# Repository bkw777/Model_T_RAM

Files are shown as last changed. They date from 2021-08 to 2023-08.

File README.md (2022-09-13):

# Model_T_RAM
8K RAM module for "Model T Computers"  
* TRS-80 Model 100  
* Kyotronic KC-85  
* NEC PC-8201  
* Olivetti M10  

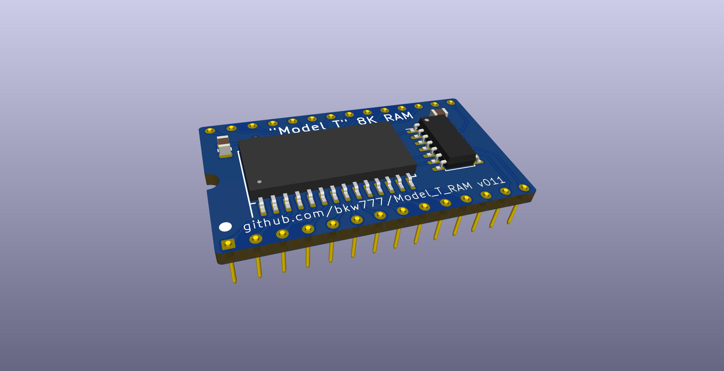
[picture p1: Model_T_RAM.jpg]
  


Gerbers available in [releases](../../releases/latest).

[PCB from OSHPark](https://oshpark.com/shared_projects/dh91gDhY)  
[PCB from PCBWAY](https://www.pcbway.com/project/shareproject/Model_T_RAM.html)

[BOM from DigiKey](https://www.digikey.com/short/vbnv3rnf)

[How to do the legs](https://gist.github.com/bkw777/52d85d89eeff8445cc667685d05ea94d)  

The DIP row spacing is actually 725 mils not 700. It makes it annoying to solder because the rows don't line up exactly with the rows in a breadboard, but it's not an error.  
Using a set of single row socket headers in the breadboard, or even two stacked, allows the socket headers to spread a little and make it easier to hold the pins and pcb for soldering, and the finished soldered pins aren't pinched inwards too badly.

----
Thanks to Steve Adolph for advice about RAM_RST

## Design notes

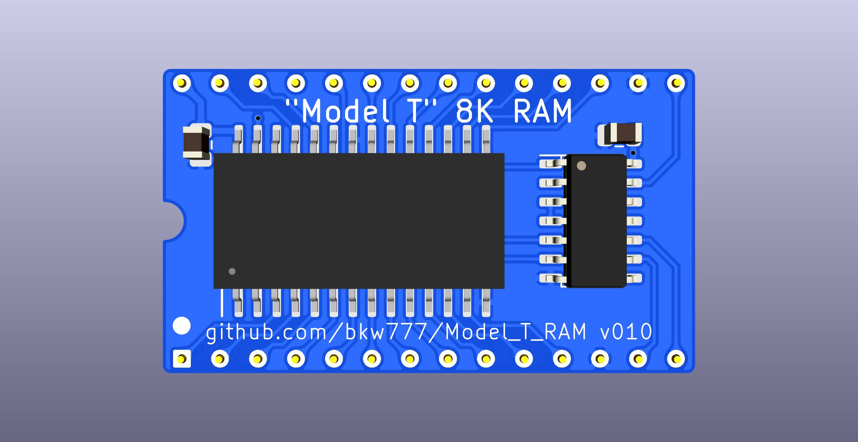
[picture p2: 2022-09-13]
Model_T_RAM_top.jpg

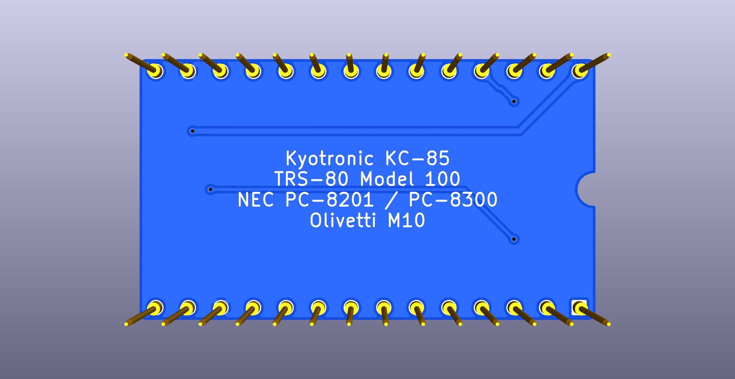
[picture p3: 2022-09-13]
Model_T_RAM_bottom.jpg

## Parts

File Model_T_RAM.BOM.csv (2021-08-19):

Index | Quantity | Part Number | Manufacturer Part Number | Description | Customer Reference | Available | Backorder | Unit Price | Extended Price USD
1 | 1 | 1450-1037-ND | AS6C6264-55SCN | IC SRAM 64KBIT PARALLEL 28SOP |  | 1 | 0 | 3.21000 | 3.21
2 | 50 | A117856CT-ND | 1544210-2 | SIL CONTACT Y1 THROUGH HOLE |  | 50 | 0 | 0.03040 | 1.52
3 | 1 | MC74HCT86ADR2GOSCT-ND | MC74HCT86ADR2G | IC GATE XOR 4CH 2-INP 14SOIC |  | 1 | 0 | 0.49000 | 0.49
4 | 2 | 732-8045-1-ND | 885012207045 | CAP CER 0.1UF 16V X7R 0805 |  | 2 | 0 | 0.10000 | 0.20

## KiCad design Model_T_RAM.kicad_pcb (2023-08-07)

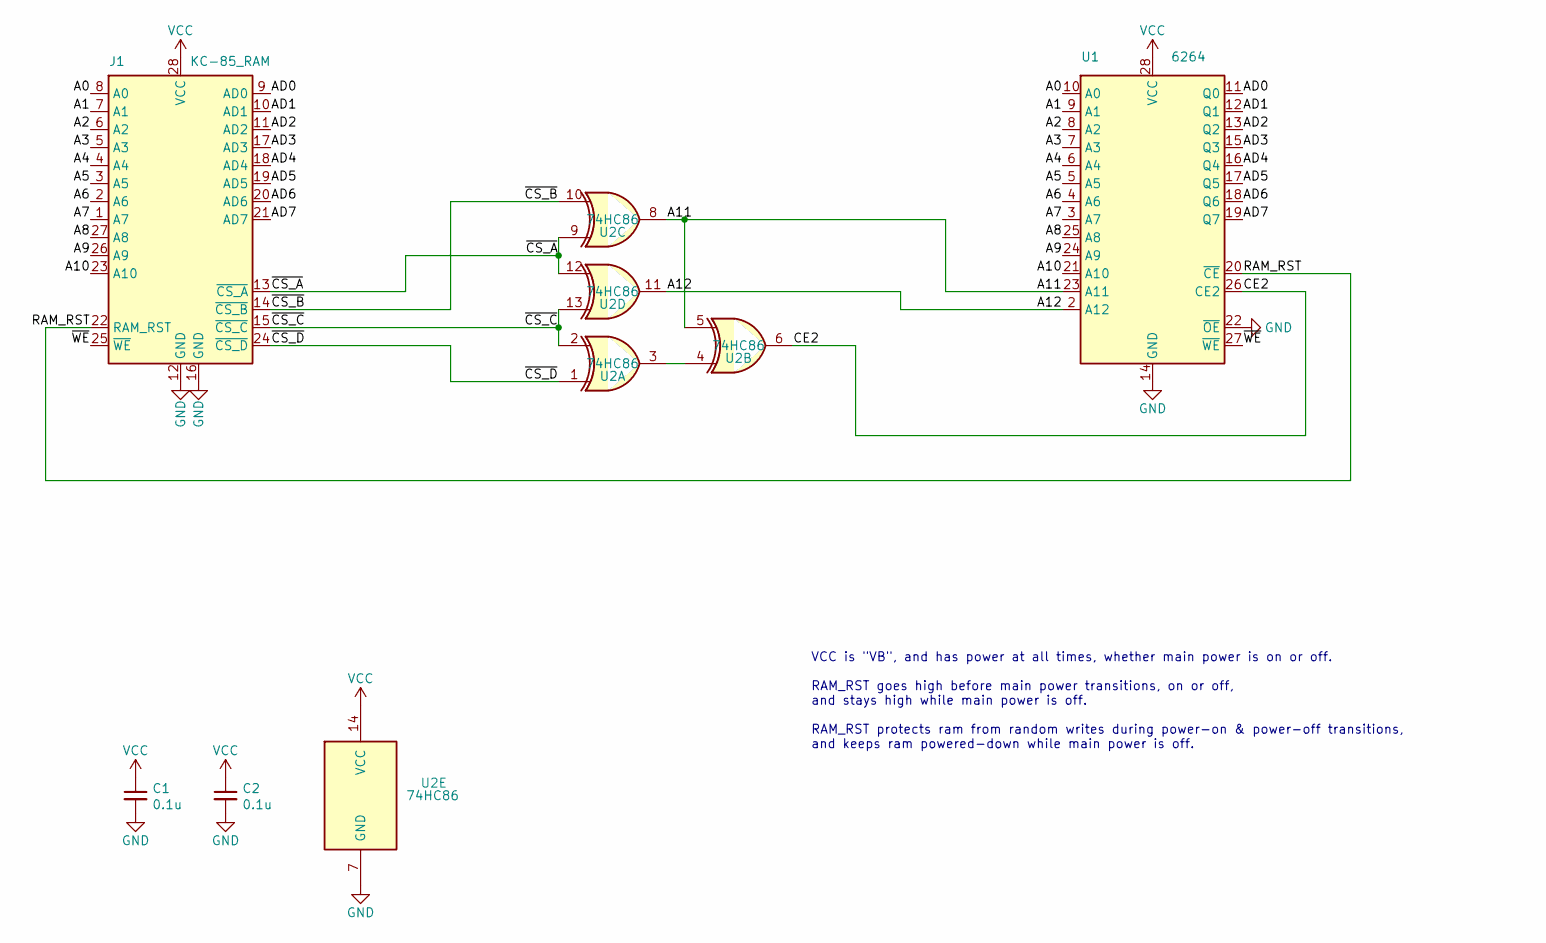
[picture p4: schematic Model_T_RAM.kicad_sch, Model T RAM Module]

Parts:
C1, C2: 0.1u; C_0805
J1: KC-85_RAM; DIP28_725mils_pcb_pins
U1: 6264; SSOP-28
U2: 74HC86; SOIC-14_4x9

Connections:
/A0: J1.8 (A0), U1.10 (A0)
/A1: J1.7 (A1), U1.9 (A1)
/A2: J1.6 (A2), U1.8 (A2)
/A3: J1.5 (A3), U1.7 (A3)
/A4: J1.4 (A4), U1.6 (A4)
/A5: J1.3 (A5), U1.5 (A5)
/A6: J1.2 (A6), U1.4 (A6)
/A7: J1.1 (A7), U1.3 (A7)
/A8: J1.27 (A8), U1.25 (A8)
/A9: J1.26 (A9), U1.24 (A9)
/A10: J1.23 (A10), U1.21 (A10)
/A11: U1.23 (A11), U2.5, U2.8
/A12: U1.2 (A12), U2.11
/AD0: J1.9 (AD0), U1.11 (Q0)
/AD1: J1.10 (AD1), U1.12 (Q1)
/AD2: J1.11 (AD2), U1.13 (Q2)
/AD3: J1.17 (AD3), U1.15 (Q3)
/AD4: J1.18 (AD4), U1.16 (Q4)
/AD5: J1.19 (AD5), U1.17 (Q5)
/AD6: J1.20 (AD6), U1.18 (Q6)
/AD7: J1.21 (AD7), U1.19 (Q7)
/CE2: U1.26 (CE2), U2.6
/RAM_RST: J1.22 (RAM_RST), U1.20 (~CE)
/~CS_A: J1.13 (~CS_A), U2.9, U2.12
/~CS_B: J1.14 (~CS_B), U2.10
/~CS_C: J1.15 (~CS_C), U2.2, U2.13
/~CS_D: J1.24 (~CS_D), U2.1
/~WE: J1.25 (~WE), U1.27 (~WE)
GND: C1.2, C2.2, J1.12 (GND), J1.16 (GND), U1.14 (GND), U1.22 (~OE), U2.7 (GND)
unnamed: U2.3, U2.4
VCC: C1.1, C2.1, J1.28 (VCC), U1.28 (VCC), U2.14 (VCC)

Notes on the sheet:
VCC is "VB", and has power at all times, whether main power is on or off. RAM_RST goes high before main power transitions, on or off, and stays high while main power is off. RAM_RST protects ram from random writes during power-on & power-off transitions, and keeps ram powered-down while main power 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

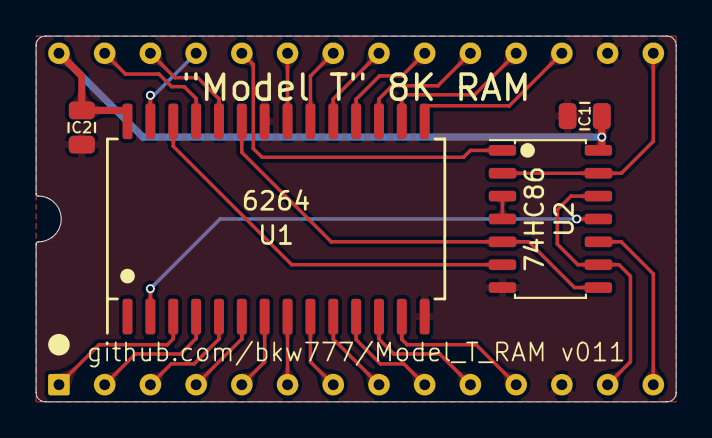
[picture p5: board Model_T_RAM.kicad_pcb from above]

Board: 2 copper layers, 35.6 x 20.3 mm, 5 parts (0 on the bottom side), 31 nets.

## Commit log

2021-04-20 v002 fewer vias
    [Model_T_RAM.kicad_pcb, Model_T_RAM_b.kicad_pcb]
2021-04-20 tiny tidying
    [Model_T_RAM.kicad_pcb, Model_T_RAM_b.kicad_pcb]
2021-04-20 switch to 74HC08
    [Model_T_RAM.BOM.csv, Model_T_RAM.kicad_pcb, Model_T_RAM.sch]
2021-04-20 tiny tidy
    [Model_T_RAM.kicad_pcb]
2021-04-21 remove 74HC86 b version
    [Model_T_RAM.kicad_pcb, Model_T_RAM.sch, Model_T_RAM_b.kicad_pcb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]
2021-08-05 prettify schematic, note power problem, mothball
    [Model_T_RAM.kicad_pcb, Model_T_RAM.sch]
2021-08-05 note RAM_RST
    [Model_T_RAM.sch]
2021-08-05 update schematic export
2021-08-05 switch to 74HC86 to sleep on standby
    [Model_T_RAM.BOM.csv, Model_T_RAM.kicad_pcb, Model_T_RAM.sch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]
2021-08-05 rotate 7486
    [Model_T_RAM.kicad_pcb, Model_T_RAM.sch, Model_T_RAM_alt.kicad_pcb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]
2021-08-06 RAM_RST on /CE instead of /OE
    [Model_T_RAM.kicad_pcb, Model_T_RAM.sch, Model_T_RAM_h.kicad_pcb]
2021-08-09 update bom
    [Model_T_RAM.BOM.csv]
2021-08-19 decoupling and ground pour
    [Model_T_RAM.kicad_pcb, Model_T_RAM.sch, Model_T_RAM_h.kicad_pcb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]
2021-08-19 bom & readme
    [Model_T_RAM.BOM.csv]
2021-08-20 gold plated brass wire
2021-09-14 better routing and shielding
    [Model_T_RAM.kicad_pcb]
2022-09-13 kicad6. 725mil row spacing. pin models.
    [Model_T_RAM.kicad_pcb, Model_T_RAM.kicad_sch, Model_T_RAM.sch]
2022-09-21 add type b variant
    [Model_T_RAM.kicad_pcb, Model_T_RAM_type_b.kicad_pcb, Model_T_RAM_type_b.kicad_sch]
2023-08-07 kicad 7
    [Model_T_RAM.kicad_pcb, Model_T_RAM.kicad_sch, Model_T_RAM_type_b.kicad_pcb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]
